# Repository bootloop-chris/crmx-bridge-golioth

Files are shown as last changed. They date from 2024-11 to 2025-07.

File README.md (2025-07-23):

# CRMX Bridge

An early demo of the [BootLoop Agent](https://bootloop.ai)!

*This repo is forked from a personal project of mine [https://github.com/chris-markus/crmx-bridge](https://github.com/chris-markus/crmx-bridge). Some clean-up commits added and upgraded to work with the most recent version of the IDF.*

Commit [77b8aad](https://github.com/bootloop-chris/crmx-bridge-golioth/commit/77b8aad5b4f520016bc5265554ae8e2e5ca4bd7b) was entirely generated and tested end-to-end by the BootLoop Agent. Email `chris [AT] bootloop [DOT] ai` for a video of the process.

---

Original README below:

Firmware and hardware for a CRMX bridge based around an ESP32s3 and a [TimoTwo module](https://lumenradio.com/products/timotwo/).

## Caveats

This is a personal project under active development. There are known (and probably unknown) bugs in the hardware. It has been open-sourced for visibility but use the hardware and firmware at your own risk!

### Known Issues

* The power button circuit has no memory outside of the microcontroller, so while downloading firmware, one of two things must be done:
  * Jump J105 to disable the power button circuit and unconditionally power the device while USB is connected
  * Hold down the power button for the duration of the software update

## Contents

* [crmx-bridge](./crmx-bridge/) - Hardware design files for the main PCBA
* [crmx-bridge-hmi](./crmx-bridge-hmi/) - Hardware design files for the Interface PCBA
* [crmx-bridge-firmware](./crmx-bridge-firmware/) - Firmware for the ESP32s3

## Firmware

Note that the firmware is pretty incomplete. It has a subset of functionality (can forward wired DMX to CRMX) but lacks control over most settings via the HMI among other omissions.

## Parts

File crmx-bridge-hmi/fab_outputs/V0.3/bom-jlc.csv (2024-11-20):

Designator | Footprint | Quantity | Value | LCSC Part #
J101 | AFC07S16FCC00 | 1 | AFC07-S16FCC-00 | C11053
R205, R207, R208 | 0402 | 3 | 10k | C25744
R206 | 0402 | 1 | 0R | C17168
R209, R210, R211 | 0603 | 3 | 150 | C22808
S201, S202, S203 | TS1187ABAB | 3 | TS-1187A-B-A-B | C318884

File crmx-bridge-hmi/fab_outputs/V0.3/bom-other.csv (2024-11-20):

Designator | Footprint | Quantity | Value | LCSC Part #
D201 | ASMBMTB00A3A2 | 1 | ASMB-MTB0-0A3A2
J201 | OLED_1.3 | 1 | Conn_01x04_Pin
U201 | PEC12R-4XXXF-SXXXX | 1 | PEC12R-4215F-S0024

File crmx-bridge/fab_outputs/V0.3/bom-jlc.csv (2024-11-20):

Designator | Footprint | Quantity | Value | LCSC Part #
C101, C102, C104, C106, C113, C114 | 0402 | 6 | 100nF | C1525
C103, C110, C111, C112 | 1206 | 4 | 22uF | C12891
C105 | 0603 | 1 | 1uF | C15849
C107 | 0603 | 1 | 10uF (50V) | C96446
C108 | 0402 | 1 | 100nF (50V) | C1525
C109 | 0603 | 1 | 100pF | C14858
C117 | 1206 | 1 | DNP | C12891
D102, D103 | D_SOD-323 | 2 | D | C191023
FB102 | 0805 | 1 | FerriteBead | C1015
IC101 | ESP32S3WROOM1UN4R2 | 1 | ESP32-S3-WROOM-1U-N4R2 | C3013942
J103 | USB_C_Receptacle_HRO_TYPE-C-31-M-12 | 1 | USB_C_Receptacle_USB2.0_16P | C165948
J106 | AFC07S16FCC00 | 1 | AFC07-S16FCC-00 | C11053
Q101 | DMTH8008LFGQ7 | 1 | DMP4025SFGQ-13 | C461091
Q102 | SOT-23 | 1 | AO3400A | C20917
R101, R102, R111, R112 | 0402 | 4 | 4k7 | C25900
R103 | 0603 | 1 | 120R (1%) | C22787
R104, R105 | 0603 | 2 | 560R (1%) | C23204
R106 | 0402 | 1 | 0R | C17168
R107, R110, R113, R121, R122, R124, R126, R127, R136 | 0402 | 9 | 10k | C25744
R108, R109 | 0603 | 2 | 27 | C25190
R115 | 0402 | 1 | 100k (1%) | C25741
R116 | 0603 | 1 | 2R | C22977
R117, R118 | 0402 | 2 | 47k (1%) | C25792
R119, R120 | 0402 | 2 | 5k1 (1%) | C25905
R123 | 0603 | 1 | 120R | C22787
R125 | 0603 | 1 | 10R (1%) | C22859
R132, R137, R138, R139, R140 | 0402 | 5 | 49R9 | C25120
R133 | 0402 | 1 | 33k | C25779
R135 | 0402 | 1 | 51k | C25794
S101, S102 | TS1187ABAB | 2 | TS-1187A-B-A-B | C318884
U102 | TSOT-23-6 | 1 | AP63200WU | C2071868
U103, U105 | SOIC-16W_7.5x10.3mm_P1.27mm | 2 | ISO3088DW | C39386
U104 | SOT-23-6 | 1 | SRV05-4 | C85364

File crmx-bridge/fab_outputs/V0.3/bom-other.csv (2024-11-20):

Designator | Footprint | Quantity | Value | LCSC Part #
J102 | Jack_XLR_Neutrik_NC3FAAH2_Horizontal | 1 | NC3FAAH2
J104 | Jack_XLR_Neutrik_NC3MAAH_Horizontal | 1 | NC3MAAH
J105 | PinHeader_1x02_P2.54mm_Vertical | 1 | Conn_01x02_Pin
L101 | L_Bourns_SRP7028A_7.3x6.6mm | 1 | 6u8H
R114 | 0402 | 1 | DNP
R134 | 0402 | 1 | DNP
TP101, TP102, TP103 | TestPoint_Pad_D1.5mm | 3 | TestPoint
U101 | MODULE_TIMOTWO | 1 | TIMOTWO
U106 | Converter_DCDC_TRACO_TEA1-xxxx_THT | 1 | TEA1-0505

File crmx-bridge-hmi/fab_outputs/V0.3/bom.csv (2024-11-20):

Designator | Footprint | Quantity | Value | LCSC Part #
D201 | ASMBMTB00A3A2 | 1 | ASMB-MTB0-0A3A2
J101 | AFC07S16FCC00 | 1 | AFC07-S16FCC-00 | C11053
J201 | OLED_1.3 | 1 | Conn_01x04_Pin
R205, R207, R208 | 0402 | 3 | 10k | C25744
R206 | 0402 | 1 | 0R | C17168
R209, R210, R211 | 0603 | 3 | 150 | C22808
S201, S202, S203 | TS1187ABAB | 3 | TS-1187A-B-A-B | C318884
U201 | PEC12R-4XXXF-SXXXX | 1 | PEC12R-4215F-S0024

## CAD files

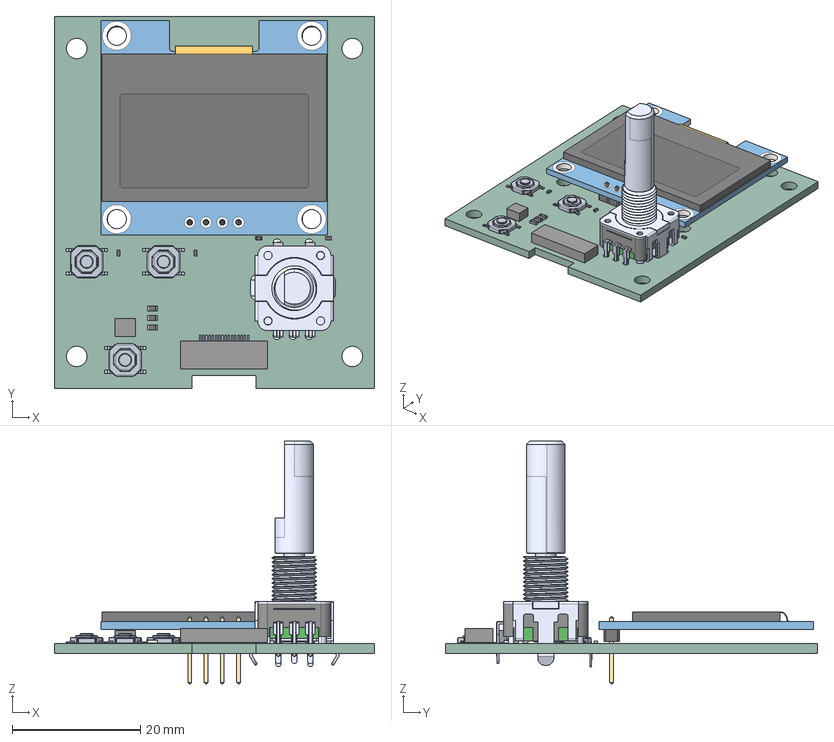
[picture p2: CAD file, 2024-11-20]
crmx-bridge-hmi/design_outputs/crmx-bridge-hmi-PCBA_V0.3.step
50.0 x 58.0 x 37.9 mm
AZ-Delivery - OLED13 IIC
R_0402_1005Metric x 4
ASSEMBLY x 2
TS-1187A-X-A-X x 3
PEC11R-4225F-S0024
R_0603_1608Metric x 3
crmx-bridge-hmi_PCB

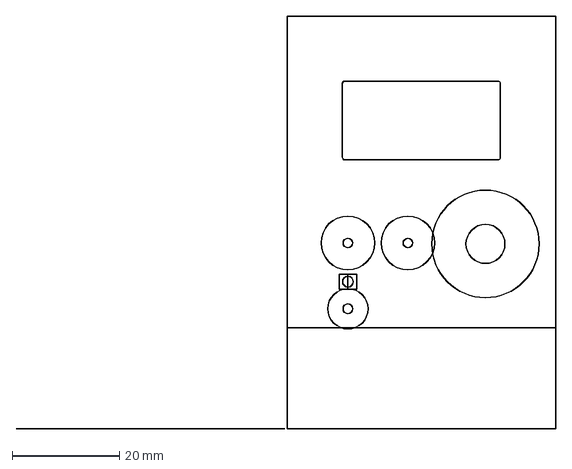
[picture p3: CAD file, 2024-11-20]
crmx-bridge/design_outputs/HMI Layout test 1.dxf
100.5 x 76.8 mm

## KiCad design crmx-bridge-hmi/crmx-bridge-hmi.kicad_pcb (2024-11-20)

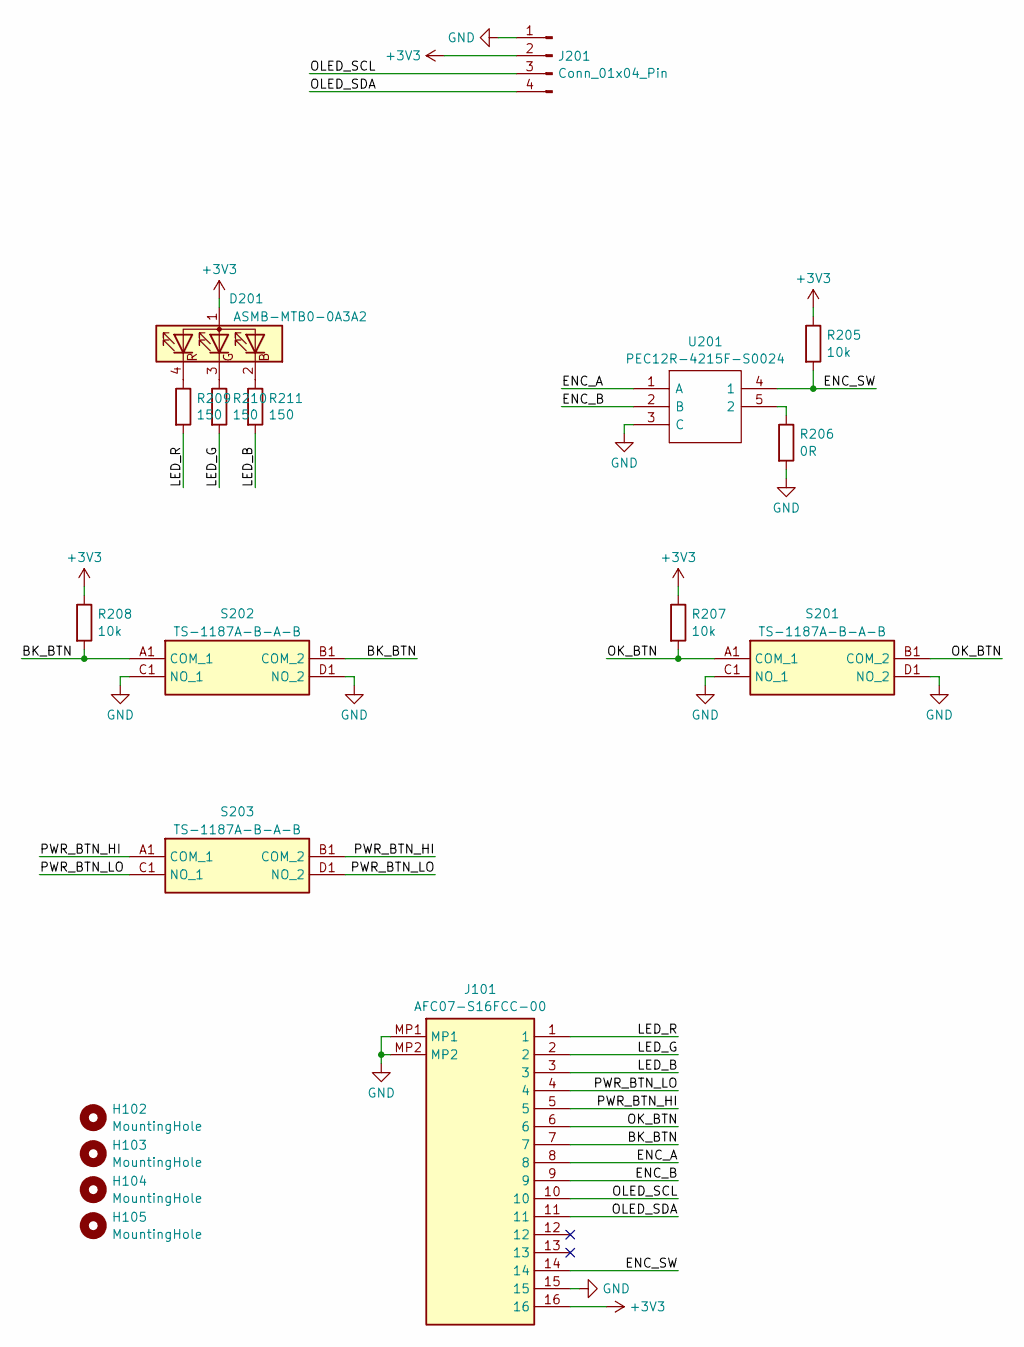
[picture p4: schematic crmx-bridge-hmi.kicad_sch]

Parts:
D201: ASMB-MTB0-0A3A2; ASMBMTB00A3A2
H102, H103, H104, H105: MountingHole; MountingHole_3.2mm_M3
J101: AFC07-S16FCC-00; AFC07S16FCC00; Manufacturer_Part_Number AFC07-S16FCC-00; LCSC C11053
J201: Conn_01x04_Pin; OLED_1.3
R205, R207, R208: 10k; R_0402_1005Metric; LCSC C25744
R206: 0R; R_0402_1005Metric; LCSC C17168
R209, R210, R211: 150; R_0603_1608Metric; LCSC C22808
S201, S202, S203: TS-1187A-B-A-B; TS1187ABAB; Manufacturer_Part_Number TS-1187A-B-A-B; LCSC C318884
U201: PEC12R-4215F-S0024; PEC12R-4XXXF-SXXXX; Manufacturer_Part_Number PEC12R-4215F-S0024; Mouser Part Number 652-PEC12R-4215F-S24

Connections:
+3V3: D201.1 (A), J101.16, J201.2, R205.1, R207.1, R208.1
/BK_BTN: J101.7, R208.2, S202.A1 (COM_1), S202.B1 (COM_2)
/ENC_A: J101.8, U201.1 (A)
/ENC_B: J101.9, U201.2 (B)
/ENC_SW: J101.14, R205.2, U201.4 (1)
/LED_B: J101.3, R211.2
/LED_G: J101.2, R210.2
/LED_R: J101.1, R209.2
/OK_BTN: J101.6, R207.2, S201.A1 (COM_1), S201.B1 (COM_2)
/OLED_SCL: J101.10, J201.3
/OLED_SDA: J101.11, J201.4
/PWR_BTN_HI: J101.5, S203.A1 (COM_1), S203.B1 (COM_2)
/PWR_BTN_LO: J101.4, S203.C1 (NO_1), S203.D1 (NO_2)
GND: J101.15, J101.MP1, J101.MP2, J201.1, R206.2, S201.C1 (NO_1), S201.D1 (NO_2), S202.C1 (NO_1), S202.D1 (NO_2), U201.3 (C)
unnamed: D201.2 (BK), R211.1
unnamed: D201.3 (GK), R210.1
unnamed: D201.4 (RK), R209.1
unnamed: R206.1, U201.5 (2)

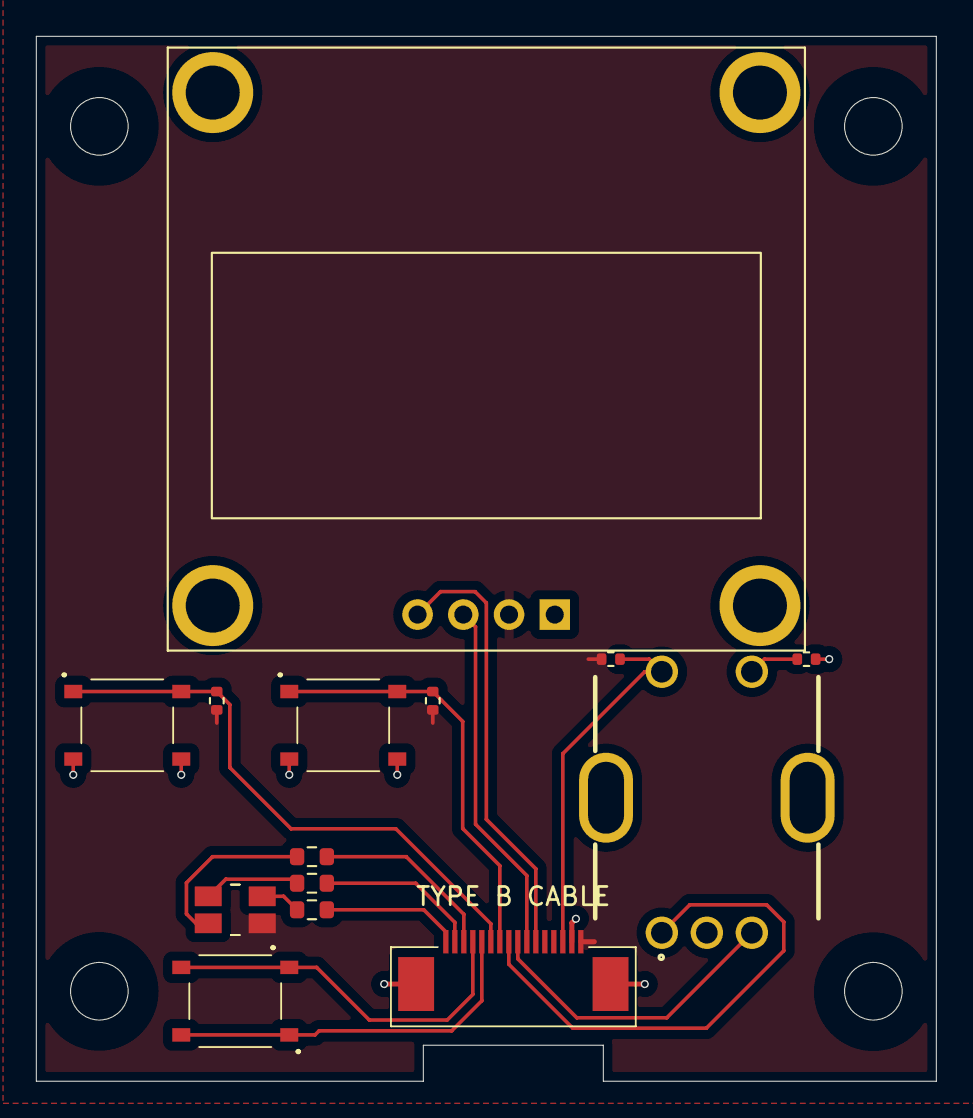
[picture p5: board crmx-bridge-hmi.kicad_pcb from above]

Board: 2 copper layers, 50.0 x 58.0 mm, 18 parts (0 on the bottom side), 18 nets.

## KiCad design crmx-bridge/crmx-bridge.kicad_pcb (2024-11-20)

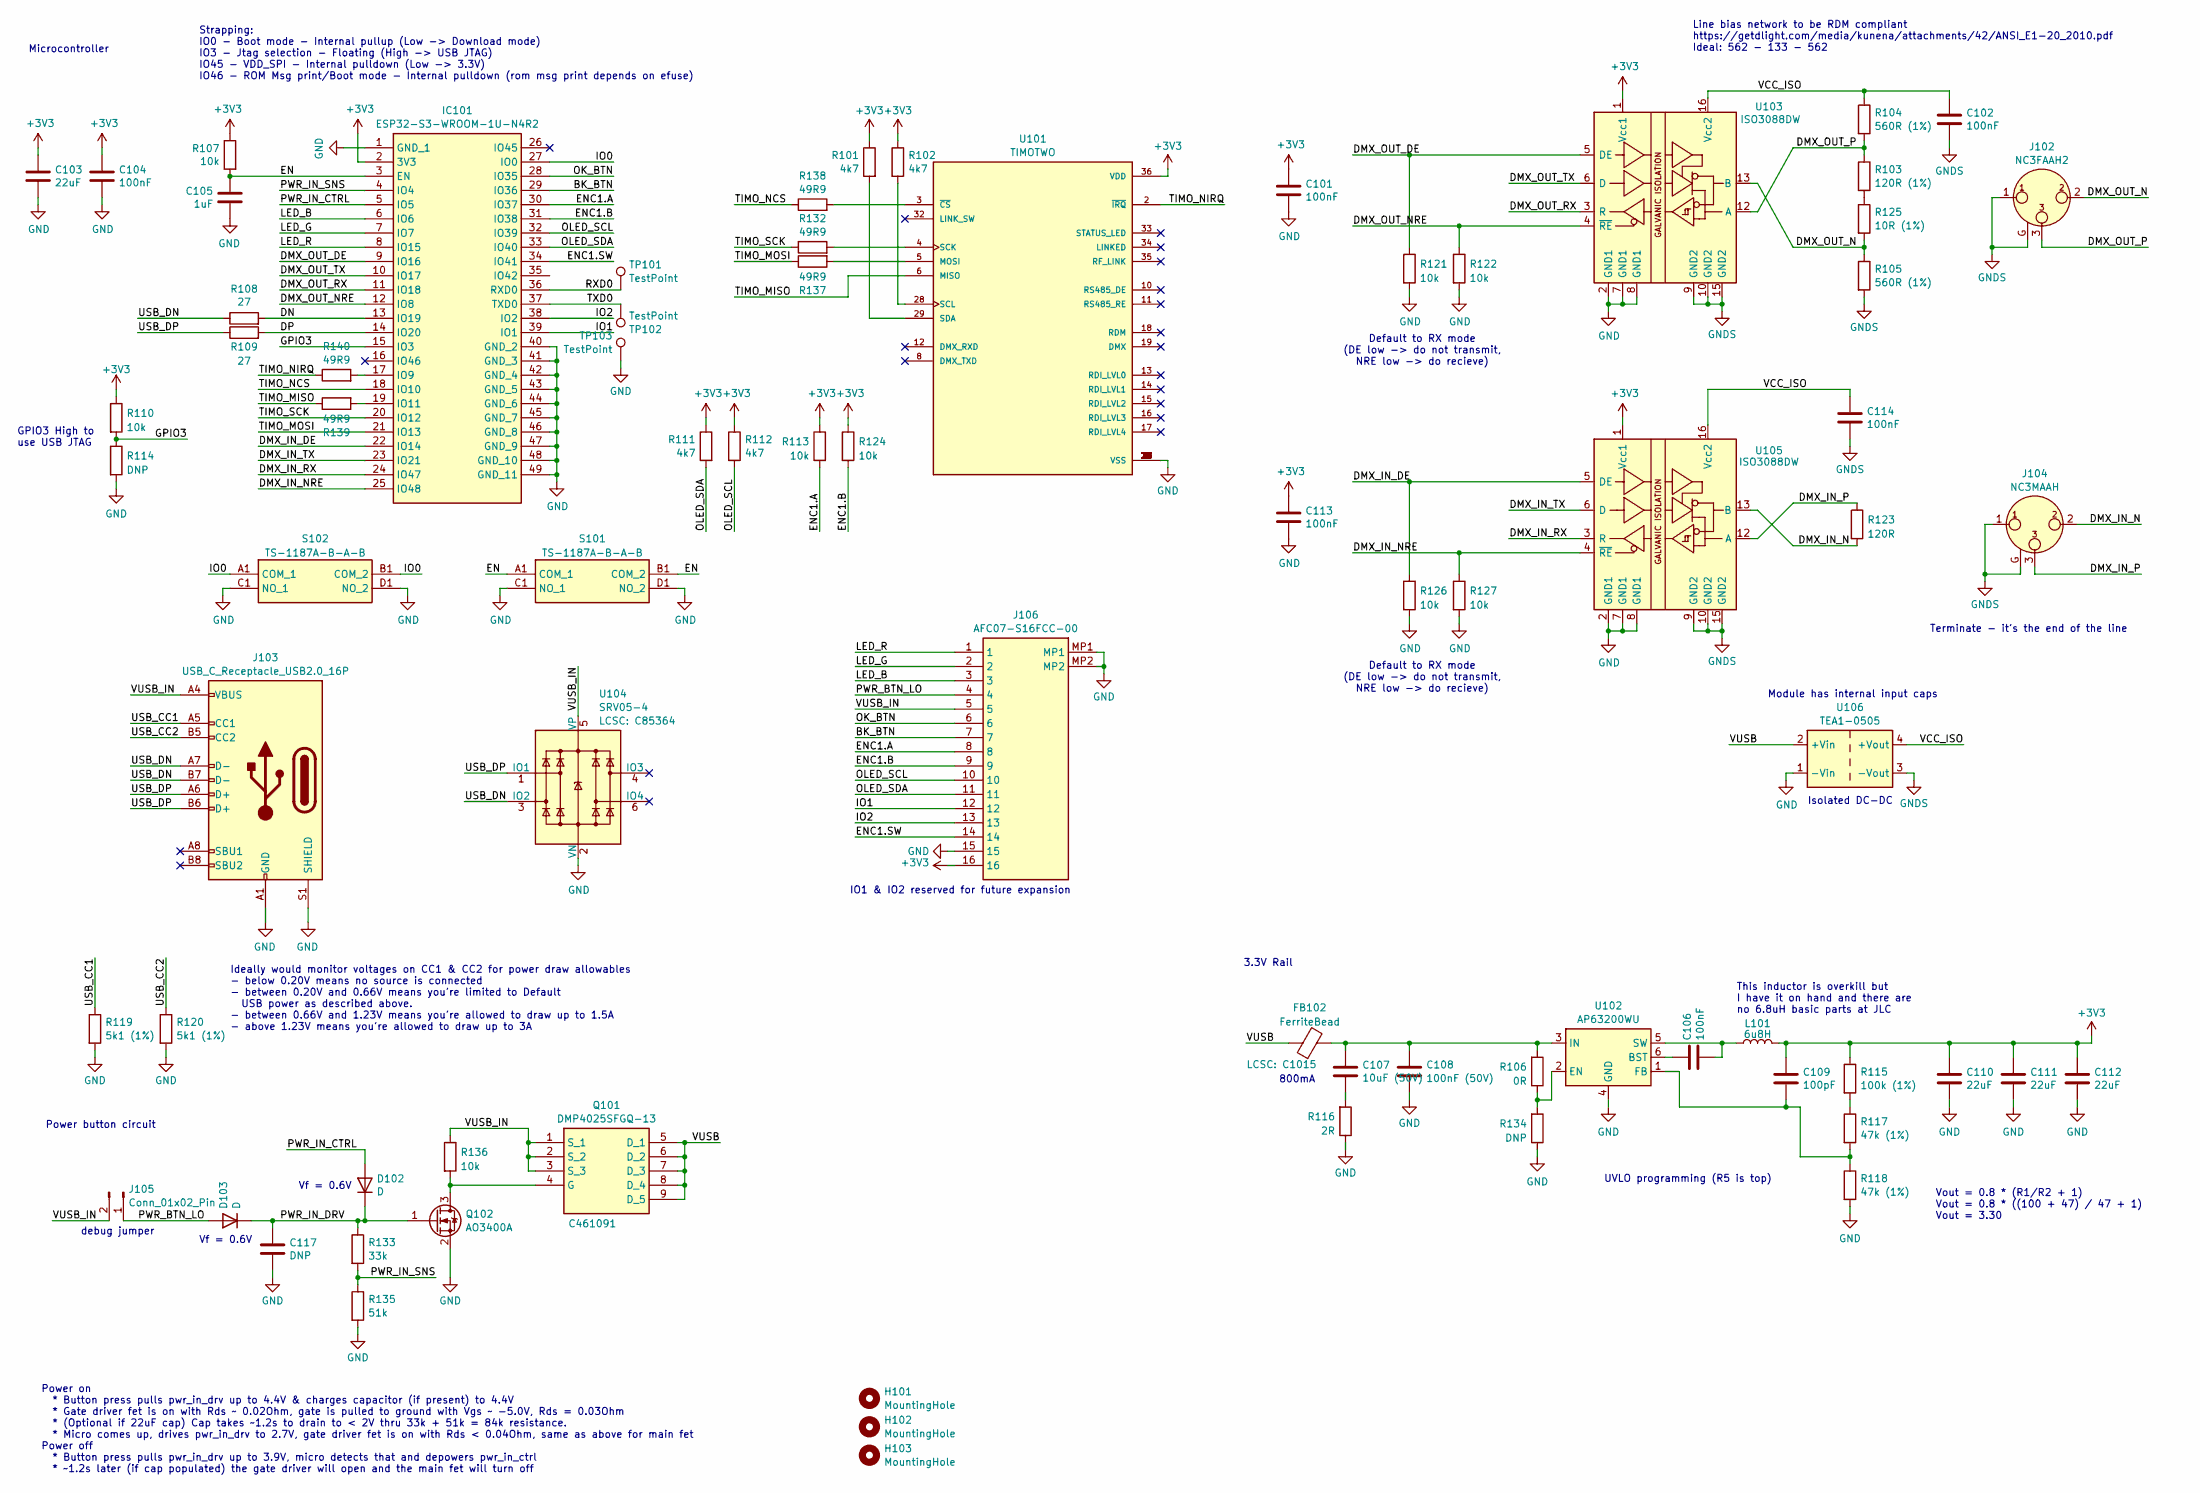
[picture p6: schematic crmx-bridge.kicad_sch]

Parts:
C101, C102, C104, C106, C113, C114: 100nF; C_0402_1005Metric; LCSC C1525
C103, C110, C111, C112: 22uF; C_1206_3216Metric; LCSC C12891
C105: 1uF; C_0603_1608Metric; LCSC C15849
C107: 10uF (50V); C_0603_1608Metric; LCSC C96446
C108: 100nF (50V); C_0402_1005Metric; LCSC C1525
C109: 100pF; C_0603_1608Metric; LCSC C14858
C117: DNP; C_1206_3216Metric; LCSC C12891
D102, D103: D; D_SOD-323; LCSC C191023
FB102: FerriteBead; C_0805_2012Metric; LCSC C1015
H101, H102, H103: MountingHole; MountingHole_3.2mm_M3
IC101: ESP32-S3-WROOM-1U-N4R2; ESP32S3WROOM1UN4R2; Manufacturer_Part_Number ESP32-S3-WROOM-1U-N4R2; Mouser Part Number 356-ESP32S3WRM1UN4R2
J102: NC3FAAH2; Jack_XLR_Neutrik_NC3FAAH2_Horizontal
J103: USB_C_Receptacle_USB2.0_16P; USB_C_Receptacle_HRO_TYPE-C-31-M-12; LCSC C165948
J104: NC3MAAH; Jack_XLR_Neutrik_NC3MAAH_Horizontal
J105: Conn_01x02_Pin; PinHeader_1x02_P2.54mm_Vertical
J106: AFC07-S16FCC-00; AFC07S16FCC00; Manufacturer_Part_Number AFC07-S16FCC-00; LCSC C11053
L101: 6u8H; L_Bourns_SRP7028A_7.3x6.6mm
Q101: DMP4025SFGQ-13; DMTH8008LFGQ7; Manufacturer_Part_Number DMPH4029LFGQ-13; Mouser Part Number 621-DMPH4029LFGQ-13
Q102: AO3400A; SOT-23; LCSC C20917
R101, R102, R111, R112: 4k7; R_0402_1005Metric; LCSC C25900
R103: 120R (1%); R_0603_1608Metric; LCSC C22787
R104, R105: 560R (1%); R_0603_1608Metric; LCSC C23204
R106: 0R; R_0402_1005Metric; LCSC C17168
R107, R110, R113, R121, R122, R124, R126, R127, R136: 10k; R_0402_1005Metric; LCSC C25744
R108, R109: 27; R_0603_1608Metric; LCSC C25190
R114, R134: DNP; R_0402_1005Metric
R115: 100k (1%); R_0402_1005Metric; LCSC C25741
R116: 2R; R_0603_1608Metric; LCSC C22977
R117, R118: 47k (1%); R_0402_1005Metric; LCSC C25792
R119, R120: 5k1 (1%); R_0402_1005Metric; LCSC C25905
R123: 120R; R_0603_1608Metric; LCSC C22787
R125: 10R (1%); R_0603_1608Metric; LCSC C22859
R132, R137, R138, R139, R140: 49R9; R_0402_1005Metric; LCSC C25120
R133: 33k; R_0402_1005Metric; LCSC C25779
R135: 51k; R_0402_1005Metric; LCSC C25794
S101, S102: TS-1187A-B-A-B; TS1187ABAB; Manufacturer_Part_Number TS-1187A-B-A-B; LCSC C318884
TP101, TP102, TP103: TestPoint; TestPoint_Pad_D1.5mm
U101: TIMOTWO; MODULE_TIMOTWO; PARTREV N/A
U102: AP63200WU; TSOT-23-6; LCSC C2071868
U103, U105: ISO3088DW; SOIC-16W_7.5x10.3mm_P1.27mm; LCSC C39386
U104: SRV05-4; SOT-23-6; LCSC C85364
U106: TEA1-0505; Converter_DCDC_TRACO_TEA1-xxxx_THT

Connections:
+3V3: C101.1, C103.1, C104.1, C109.1, C110.1, C111.1, C112.1, C113.1, IC101.2 (3V3), J106.16, L101.2, R101.1, R102.1, R107.1, R110.1, R111.1, R112.1, R113.1, R115.1, R124.1, U101.36 (VDD), U103.1 (Vcc1), U105.1 (Vcc1)
/BK_BTN: IC101.29 (IO36), J106.7
/DMX_IN_DE: IC101.22 (IO14), R126.1, U105.5 (DE)
/DMX_IN_N: J104.2, R123.2, U105.13 (B)
/DMX_IN_NRE: IC101.25 (IO48), R127.1, U105.4 (~RE)
/DMX_IN_P: J104.3, R123.1, U105.12 (A)
/DMX_IN_RX: IC101.24 (IO47), U105.3 (R)
/DMX_IN_TX: IC101.23 (IO21), U105.6 (D)
/DMX_OUT_DE: IC101.9 (IO16), R121.1, U103.5 (DE)
/DMX_OUT_N: J102.2, R105.1, R125.2, U103.13 (B)
/DMX_OUT_NRE: IC101.12 (IO8), R122.1, U103.4 (~RE)
/DMX_OUT_P: J102.3, R103.1, R104.2, U103.12 (A)
/DMX_OUT_RX: IC101.11 (IO18), U103.3 (R)
/DMX_OUT_TX: IC101.10 (IO17), U103.6 (D)
/DN: IC101.13 (IO19), R108.2
/DP: IC101.14 (IO20), R109.2
/EN: C105.1, IC101.3 (EN), R107.2, S101.A1 (COM_1), S101.B1 (COM_2)
/ENC1.A: IC101.30 (IO37), J106.8, R113.2
/ENC1.B: IC101.31 (IO38), J106.9, R124.2
/ENC1.SW: IC101.34 (IO41), J106.14
/GPIO3: IC101.15 (IO3), R110.2, R114.1
/IO0: IC101.27 (IO0), S102.A1 (COM_1), S102.B1 (COM_2)
/IO1: IC101.39 (IO1), J106.12
/IO2: IC101.38 (IO2), J106.13
/LED_B: IC101.6 (IO6), J106.3
/LED_G: IC101.7 (IO7), J106.2
/LED_R: IC101.8 (IO15), J106.1
/OK_BTN: IC101.28 (IO35), J106.6
/OLED_SCL: IC101.32 (IO39), J106.10, R112.2
/OLED_SDA: IC101.33 (IO40), J106.11, R111.2
/PWR_BTN_LO: D103.2 (A), J105.1, J106.4
/PWR_IN_CTRL: D102.2 (A), IC101.5 (IO5)
/PWR_IN_DRV: C117.1, D102.1 (K), D103.1 (K), Q102.1 (G), R133.1
/PWR_IN_SNS: IC101.4 (IO4), R133.2, R135.1
/RXD0: IC101.36 (RXD0), TP101.1
/TIMO_MISO: R139.1, U101.6 (MISO)
/TIMO_MOSI: IC101.21 (IO13), R137.1
/TIMO_NCS: IC101.18 (IO10), R138.1
/TIMO_NIRQ: R140.1, U101.2 (~IRQ)
/TIMO_SCK: IC101.20 (IO12), R132.1
/TXD0: IC101.37 (TXD0), TP102.1
/USB_CC1: J103.A5 (CC1), R119.1
/USB_CC2: J103.B5 (CC2), R120.1
/USB_DN: J103.A7 (D-), J103.B7 (D-), R108.1, U104.3 (IO2)
/USB_DP: J103.A6 (D+), J103.B6 (D+), R109.1, U104.1 (IO1)
/VCC_ISO: C102.1, C114.1, R104.1, U103.16 (Vcc2), U105.16 (Vcc2), U106.4 (+Vout)
/VUSB: FB102.1, Q101.5 (D_1), Q101.6 (D_2), Q101.7 (D_3), Q101.8 (D_4), Q101.9 (D_5), U106.2 (+Vin)
/VUSB_IN: J103.A4 (VBUS), J103.A9 (VBUS), J103.B4 (VBUS), J103.B9 (VBUS), J105.2, J106.5, Q101.1 (S_1), Q101.2 (S_2), Q101.3 (S_3), R136.1, U104.5 (VP)
GND: C101.2, C103.2, C104.2, C105.2, C108.2, C110.2, C111.2, C112.2, C113.2, C117.2, IC101.1 (GND_1), IC101.40 (GND_2), IC101.41 (GND_3), IC101.42 (GND_4), IC101.43 (GND_5), IC101.44 (GND_6), IC101.45 (GND_7), IC101.46 (GND_8), IC101.47 (GND_9), IC101.48 (GND_10), IC101.49 (GND_11), J103.A1 (GND), J103.A12 (GND), J103.B1 (GND), J103.B12 (GND), J103.S1 (SHIELD), J106.15, J106.MP1, J106.MP2, Q102.2 (S), R114.2, R116.1, R118.2, R119.2, R120.2, R121.2, R122.2, R126.2, R127.2, R134.1, R135.2, S101.C1 (NO_1), S101.D1 (NO_2), S102.C1 (NO_1), S102.D1 (NO_2), TP103.1, U101.1 (VSS), U101.7 (VSS), U101.9 (VSS), U101.22 (VSS), U101.23 (VSS), U101.24 (VSS), U101.25 (VSS), U101.26 (VSS), U101.27 (VSS), U101.30 (VSS), U101.37 (VSS), U102.4 (GND), U103.2 (GND1), U103.7 (GND1), U103.8 (GND1), U104.2 (VN), U105.2 (GND1), U105.7 (GND1), U105.8 (GND1), U106.1 (-Vin)
GNDS: C102.2, C114.2, J102.1, J102.G, J104.1, J104.G, R105.2, U103.9 (GND2), U103.10 (GND2), U103.15 (GND2), U105.9 (GND2), U105.10 (GND2), U105.15 (GND2), U106.3 (-Vout)
unnamed: C107.2, R116.2
unnamed: IC101.17 (IO9), R140.2
unnamed: IC101.19 (IO11), R139.2
unnamed: Q101.4 (G), Q102.3 (D), R136.2
unnamed: R103.2, R125.1
unnamed: R115.2, R117.1
unnamed: R137.2, U101.5 (MOSI)
unnamed: R132.2, U101.4 (SCK)
unnamed: R102.2, U101.28 (SCL)
unnamed: R101.2, U101.29 (SDA)
unnamed: R138.2, U101.3 (~CS)
unnamed: C106.1, U102.6 (BST)
unnamed: R106.1, R134.2, U102.2 (EN)
unnamed: C109.2, R117.2, R118.1, U102.1 (FB)
unnamed: C107.1, C108.1, FB102.2, R106.2, U102.3 (IN)
unnamed: C106.2, L101.1, U102.5 (SW)

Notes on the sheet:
Power on * Button press pulls pwr_in_drv up to 4.4V & charges capacitor (if present) to 4.4V * Gate driver fet is on with Rds ~ 0.02Ohm, gate is pulled to ground with Vgs ~ -5.0V, Rds = 0.03Ohm * (Optional if 22uF cap) Cap takes ~1.2s to drain to < 2V thru 33k + 51k = 84k resistance. * Micro comes 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
Vout = 0.8 * (R1/R2 + 1) Vout = 0.8 * ((100 + 47) / 47 + 1) Vout = 3.30
Vf = 0.6V
GPIO3 High to use USB JTAG
Strapping: IO0 - Boot mode - Internal pullup (Low -> Download mode) IO3 - Jtag selection - Floating (High -> USB JTAG) IO45 - VDD_SPI - Internal pulldown (Low -> 3.3V) IO46 - ROM Msg print/Boot mode - Internal pulldown (rom msg print depends on efuse)
debug jumper
3.3V Rail
Isolated DC-DC
IO1 & IO2 reserved for future expansion
Ideally would monitor voltages on CC1 & CC2 for power draw allowables - below 0.20V means no source is connected - between 0.20V and 0.66V means you're limited to Default USB power as described above. - between 0.66V and 1.23V means you're allowed to draw up to 1.5A - above 1.23V means you're allow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
UVLO programming (R5 is top)
800mA
Default to RX mode (DE low -> do not transmit, NRE low -> do recieve)
Power button circuit
Terminate - it's the end of the line
Microcontroller
Module has internal input caps
Line bias network to be RDM compliant https://getdlight.com/media/kunena/attachments/42/ANSI_E1-20_2010.pdf Ideal: 562 - 133 - 562
This inductor is overkill but I have it on hand and there are no 6.8uH basic parts at JLC

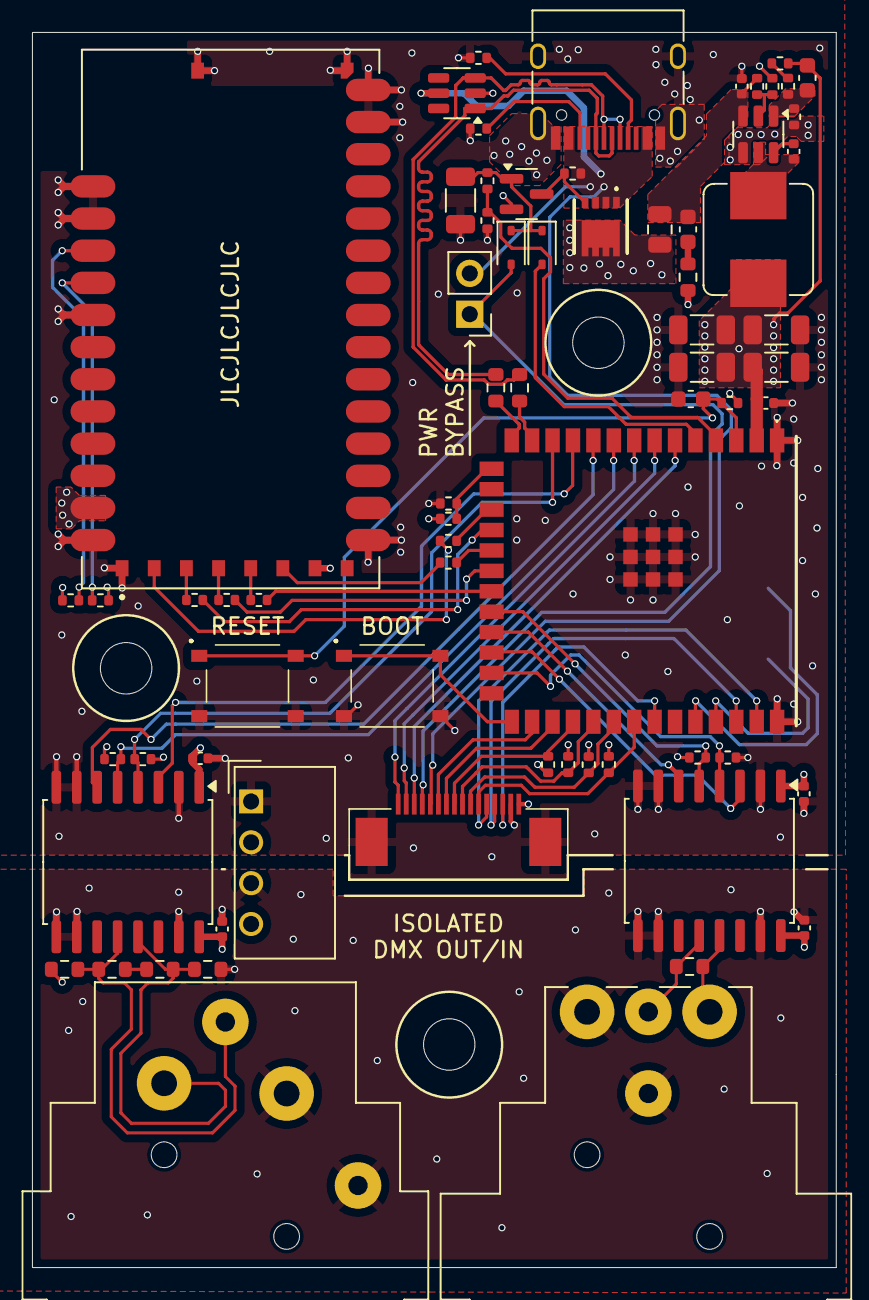
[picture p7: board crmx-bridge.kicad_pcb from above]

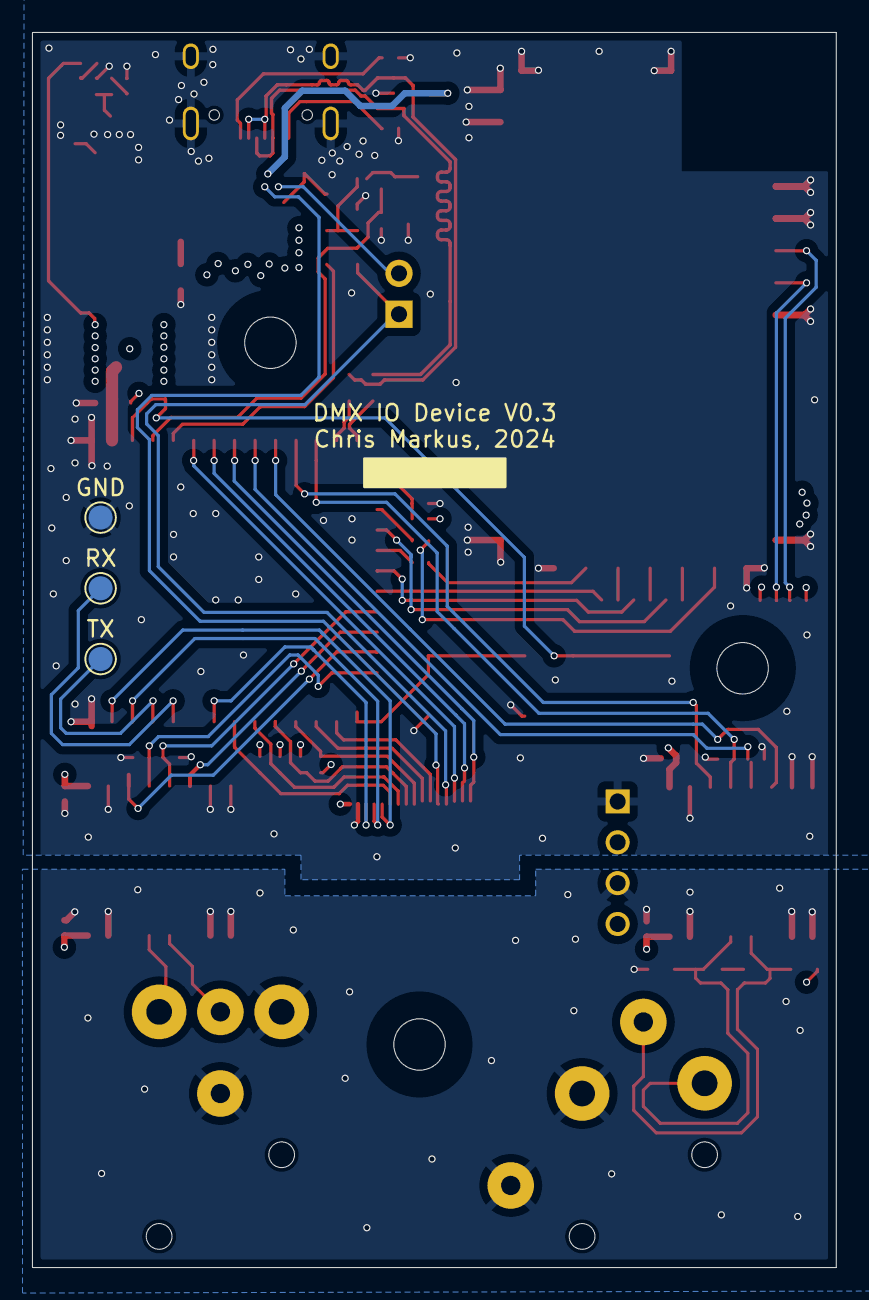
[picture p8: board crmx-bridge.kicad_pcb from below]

Board: 4 copper layers, 50.0 x 76.8 mm, 77 parts (3 on the bottom side), 66 nets.

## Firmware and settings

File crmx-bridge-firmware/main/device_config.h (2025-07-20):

#pragma once

// Default WiFi credentials (can be overridden via NVS or Golioth settings)
#define DEFAULT_WIFI_SSID    ""  // Set your default WiFi SSID here
#define DEFAULT_WIFI_PASS    ""  // Set your default WiFi password here

// Default Golioth credentials (can be overridden via NVS)
#define DEFAULT_GOLIOTH_PSK_ID  ""  // Set your Golioth PSK ID here
#define DEFAULT_GOLIOTH_PSK     ""  // Set your Golioth PSK here - You'll need to provide this

// Telemetry reporting interval
#define TELEMETRY_INTERVAL_MS   (30 * 1000)  // 30 seconds

// Enable/disable features
#define ENABLE_GOLIOTH_LOGS     1
#define ENABLE_TELEMETRY        1
#define ENABLE_OTA_UPDATES      1

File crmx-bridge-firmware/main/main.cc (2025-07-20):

#include "DmxSwitcher.h"
#include "SettingsHandler.h"
#include "TimoInterface.h"
#include "wifi_task.h"
#include "wifi_manager.h"
#include "device_config.h"
#include "driver/gpio.h"
#include "driver/i2c_master.h"
#include "driver/ledc.h"
#include "driver/spi_master.h"
#include "esp_adc/adc_cali.h"
#include "esp_adc/adc_cali_scheme.h"
#include "esp_adc/adc_oneshot.h"
#include "esp_dmx.h"
#include "esp_err.h"
#include "esp_lcd_panel_io.h"
#include "esp_lcd_panel_ops.h"
#include "esp_lcd_panel_vendor.h"
#include "esp_log.h"
#include "esp_lvgl_port.h"
#include "esp_timer.h"
#include "freertos/FreeRTOS.h"
#include "freertos/task.h"
#include "limits.h"
#include "lvgl.h"
#include "rotary_encoder.h"
#include "soc/soc_caps.h"
#include "ssd1106.h"
#include "ui/ui.h"
#include <stdio.h>
#include <stdlib.h>
#include <string.h>

#define LCD_PIXEL_CLOCK_HZ (400 * 1000)
#define PIN_NUM_SDA 40
#define PIN_NUM_SCL 39
#define PIN_NUM_RST -1
#define I2C_HW_ADDR 0x3C

// The pixel number in horizontal and vertical
#define LCD_H_RES 128
#define LCD_V_RES 64
// Bit number used to represent command and parameter
#define LCD_CMD_BITS 8
#define LCD_PARAM_BITS 8

const static char *TAG = "main";

static constexpr adc_channel_t pwr_btn_sns_chann = ADC_CHANNEL_3;
static constexpr gpio_num_t pwr_in_ctrl_pin = GPIO_NUM_37;
static constexpr int pwr_btn_press_thresh_mv = 2500;

static constexpr spi_host_device_t timo_spi_bus = SPI2_HOST;
static constexpr spi_bus_config_t spi_bus_cfg = {
    .mosi_io_num = GPIO_NUM_13,
    .miso_io_num = GPIO_NUM_11,
    .sclk_io_num = GPIO_NUM_12,
    .quadwp_io_num = -1,
    .quadhd_io_num = -1,
    .max_transfer_sz = 0,
};

// The SPI configuration for the TimoTwo CRMX Module
static constexpr TimoHardwareConfig timo_config = {
    .nirq_pin = GPIO_NUM_9,
    .spi_devcfg =
        {
            .mode = 0, // SPI mode 0 (CPOL 0, CPHA0)
            .cs_ena_pretrans = 6,
            .clock_speed_hz = 1 * 1000 * 1000, // 1 MHz
            .spics_io_num = GPIO_NUM_10,       // CS pin
            .queue_size = 1,
        },
};

TimoInterface timo_interface{timo_config};

static constexpr gpio_num_t led_r_pin = GPIO_NUM_15;
static constexpr gpio_num_t led_g_pin = GPIO_NUM_7;
static constexpr gpio_num_t led_b_pin = GPIO_NUM_6;
static constexpr gpio_num_t btn_ok_pin = GPIO_NUM_35;
static constexpr gpio_num_t btn_bk_pin = GPIO_NUM_36;
static constexpr gpio_num_t btn_enc_pin = GPIO_NUM_41;
static constexpr gpio_num_t enc_a_pin = GPIO_NUM_37;
static constexpr gpio_num_t enc_b_pin = GPIO_NUM_38;

// DMX Configuration for physical input and output ports
struct dmx_port_config_t {
  dmx_port_t port;
  int tx_pin;
  int rx_pin;
  gpio_num_t de_pin;
  gpio_num_t nre_pin;
};
static constexpr dmx_port_config_t dmx_in_cfg = {
    .port = DMX_NUM_0,
    .tx_pin = 21,
    .rx_pin = 47,
    .de_pin = GPIO_NUM_14,
    .nre_pin = GPIO_NUM_48,
};
static constexpr dmx_port_config_t dmx_out_cfg = {
    .port = DMX_NUM_1,
    .tx_pin = 17,
    .rx_pin = 18,
    .de_pin = GPIO_NUM_16,
    .nre_pin = GPIO_NUM_8,
};

// Encoder
QueueHandle_t encoder_queue = nullptr;

static void set_led_color(const RGBColor &color) {
  ledc_set_duty_and_update(LEDC_LOW_SPEED_MODE, LEDC_CHANNEL_0, color.red, 0);
  ledc_set_duty_and_update(LEDC_LOW_SPEED_MODE, LEDC_CHANNEL_1, color.green, 0);
  ledc_set_duty_and_update(LEDC_LOW_SPEED_MODE, LEDC_CHANNEL_2, color.blue, 0);
}

/**
 * DMX Task for physical DMX IO
 */
extern "C" void onboard_dmx_task(void *pvParameters) {
  DmxInterface *interface = static_cast<DmxInterface *>(pvParameters);

  if (interface == nullptr) {
    ESP_LOGE(TAG, "Invalid DMX Interface");
    return;
  }

  // First, use the default DMX configuration...
  dmx_config_t dmx_config = DMX_CONFIG_DEFAULT;

  // Install the send and recieve drivers.
  dmx_driver_install(dmx_in_cfg.port, &dmx_config, nullptr, 0);
  dmx_driver_install(dmx_out_cfg.port, &dmx_config, nullptr, 0);

  // Set the pins for both drivers.
  dmx_set_pin(dmx_in_cfg.port, dmx_in_cfg.tx_pin, dmx_in_cfg.rx_pin, -1);
  dmx_set_pin(dmx_out_cfg.port, dmx_out_cfg.tx_pin, dmx_out_cfg.rx_pin, -1);

  // Configure DE/RE pins (true = tx; false = rx).
  ESP_ERROR_CHECK(gpio_set_level(dmx_in_cfg.nre_pin, false));
  ESP_ERROR_CHECK(gpio_set_level(dmx_in_cfg.de_pin, false));
  ESP_ERROR_CHECK(gpio_set_level(dmx_out_cfg.nre_pin, true));
  ESP_ERROR_CHECK(gpio_set_level(dmx_out_cfg.de_pin, true));

  gpio_config_t dmx_io_conf = {
      .pin_bit_mask =
          (1ULL << dmx_in_cfg.de_pin) | (1ULL << dmx_in_cfg.nre_pin) |
          (1ULL << dmx_out_cfg.de_pin) | (1ULL << dmx_out_cfg.nre_pin),
      .mode = GPIO_MODE_OUTPUT,
      .pull_up_en = GPIO_PULLUP_DISABLE,
      .pull_down_en = GPIO_PULLDOWN_DISABLE,
      .intr_type = GPIO_INTR_DISABLE,
  };

  ESP_ERROR_CHECK(gpio_config(&dmx_io_conf));

  dmx_packet_t rx_meta;

  DmxPacket tx_packet;
  DmxPacket rx_packet;

  ESP_LOGI(TAG, "Finished Onboard DMX Init");

  while (true) {
    if (dmx_receive(dmx_in_cfg.port, &rx_meta, DMX_TIMEOUT_TICK)) {
      if (rx_meta.err != DMX_OK ||
          rx_meta.size > sizeof(rx_packet.full_packet)) {
        ESP_LOGE(TAG, "DMX Packet Error: %d, %zu", rx_meta.err, rx_meta.size);
      } else {
        size_t data_len = dmx_read(dmx_in_cfg.port, &rx_packet.full_packet,
                                   rx_packet.full_packet.size());
        if (data_len == rx_packet.full_packet.size()) {
          interface->send(rx_packet);
        } else {
          ESP_LOGE(TAG, "Recieved short DMX packet: %zu", data_len);
        }
      }
    }

    if (interface->recieve(tx_packet, 0)) {
      size_t written_len = dmx_write(dmx_out_cfg.port, &tx_packet.full_packet,
                                     tx_packet.full_packet.size());
      if (written_len != tx_packet.full_packet.size()) {
        ESP_LOGE(TAG, "Wrote short DMX Packet: %zu", written_len);
      }
      written_len = dmx_send(dmx_out_cfg.port);
      if (written_len != tx_packet.full_packet.size()) {
        ESP_LOGE(TAG, "Sent short DMX Packet: %zu", written_len);
      }
    }
    vTaskDelay(pdMS_TO_TICKS(2));
  }
}

/**
 * Delegate implementation to notify a task when settings are changed
 */
class TaskNotifySettingsDelegate : public SettingsChangeDelegate {
public:
  TaskNotifySettingsDelegate(TaskHandle_t _task_handle)
      : task_handle(_task_handle) {}

  void on_settings_update(const SettingsHandler &settings) override {
    if (task_handle != nullptr) {
      xTaskNotify(task_handle, true, eSetValueWithOverwrite);
    }
  }

private:
  TaskHandle_t task_handle;
};

/**
 * Construct a Timo software config from the values stored in NVS
 */
static TimoSoftwareConfig timo_config_from_settings() {
  SettingsHandler &settings = SettingsHandler::shared();

  using namespace TIMO;
  return TimoSoftwareConfig{
      .radio_en = settings.get_timo_radio_en(),
      .tx_rx_mode = settings.get_timo_tx_rx(),
      .rf_protocol = settings.rf_protocol,
      .dmx_source = DMX_SOURCE::DATA_SOURCE_T::NO_DATA,
      .rf_power = settings.tmo_opt_pwr,
      .universe_color = settings.get_universe_color(),
      .device_name = "CRMXBridge",
  };
}

/**
 * Run the TimoTwo interface
 */
extern "C" void timo_dmx_task(void *pvParameters) {
  DmxInterface *interface = static_cast<DmxInterface *>(pvParameters);

  if (interface == nullptr) {
    ESP_LOGE(TAG, "Invalid DMX Interface");
    return;
  }

  // Give TIMO a while to power on.
  vTaskDelay(pdMS_TO_TICKS(2000));

  // Initialize the SPI bus
  ESP_ERROR_CHECK(
      spi_bus_initialize(timo_spi_bus, &spi_bus_cfg, SPI_DMA_CH_AUTO));
  ESP_ERROR_CHECK(timo_interface.init(timo_spi_bus));

  // Settings are user-generated and therefore fallable. Allow boot to continue
  // even if setting settings fails.
  ESP_ERROR_CHECK_WITHOUT_ABORT(
      timo_interface.set_sw_config(timo_config_from_settings()));

  ESP_LOGI(TAG, "Finished Timo Init");

  int64_t last_print = esp_timer_get_time();

  TickType_t xLastWakeTime = xTaskGetTickCount();
  DmxPacket packet{};

  // Loop over the recieved frames and transmit them
  while (true) {
    // Interface -> recieve blocks
    if (interface->recieve(packet, pdMS_TO_TICKS(5))) {
      if (timo_interface.write_dmx(packet.full_packet.data) != ESP_OK) {
        ESP_LOGE(TAG, "Failed to write dmx from source %d",
                 static_cast<int>(packet.source));
      }
    }

    // If a notification was recieved, a settings update occurred.
    if (xTaskNotifyWait(0b1, 0, NULL, 0) == pdTRUE) {
      TimoSoftwareConfig new_config = timo_config_from_settings();
      if (new_config != timo_interface.get_sw_config()) {
        timo_interface.set_sw_config(new_config);
      }
    }

    vTaskDelayUntil(&xLastWakeTime, pdMS_TO_TICKS(2));
  }
}

void init_led() {

  static constexpr auto SPEED_MODE = LEDC_LOW_SPEED_MODE;
  static constexpr auto TIMER = LEDC_TIMER_0;

  // Prepare and then apply the LEDC PWM timer configuration
  ledc_timer_config_t ledc_timer = {
      .speed_mode = SPEED_MODE,
      .duty_resolution = LEDC_TIMER_8_BIT,
      .timer_num = TIMER,
      .freq_hz = 4000, // Set output frequency at 4 kHz
      .clk_cfg = LEDC_AUTO_CLK,
  };
  ESP_ERROR_CHECK(ledc_timer_config(&ledc_timer));

  static constexpr std::array<gpio_num_t, 3> led_pins = {
      {led_r_pin, led_g_pin, led_b_pin}};
  static constexpr std::array<ledc_channel_t, 3> led_channels = {
      {LEDC_CHANNEL_0, LEDC_CHANNEL_1, LEDC_CHANNEL_2}};

  for (size_t i = 0; i < 3; i++) {
    ledc_channel_config_t ledc_channel = {
        .gpio_num = led_pins[i],
        .speed_mode = SPEED_MODE,
        .channel = led_channels[i],
        .intr_type = LEDC_INTR_DISABLE,
        .timer_sel = TIMER,
        .duty = 0, // Set duty to 0%
        .hpoint = 0,
        .flags = {.output_invert = 1},
    };
    ESP_ERROR_CHECK(ledc_channel_config(&ledc_channel));
  }
  ESP_ERROR_CHECK(ledc_fade_func_install(0));

  set_led_color(SettingsHandler::shared().get_universe_color());
}


int16_t enc_get_new_moves() {
  static int32_t last_position = 0;

  if (!encoder_queue) {
    return 0;
  }

  rotary_encoder_event_t event = {0};
  if (xQueueReceive(encoder_queue, &event, 0) == pdTRUE) {
    const int16_t val =
        static_cast<int16_t>(last_position - event.state.position);
    last_position = event.state.position;
    return val;
  }
  return 0;
}

void encoder_read(lv_indev_t *indev, lv_indev_data_t *data) {
  data->enc_diff = enc_get_new_moves();

  if (gpio_get_level(btn_enc_pin))
    data->state = LV_INDEV_STATE_RELEASED;
  else
    data->state = LV_INDEV_STATE_PRESSED;
}

void init_lvgl() {
  // From LVGL monochrome example
  ESP_LOGI(TAG, "Initialize I2C bus");
  i2c_master_bus_handle_t i2c_bus = NULL;
  i2c_master_bus_config_t bus_config = {
      .i2c_port = I2C_NUM_0,
      .sda_io_num = GPIO_NUM_40,
      .scl_io_num = GPIO_NUM_39,
      .clk_source = I2C_CLK_SRC_DEFAULT,
      .glitch_ignore_cnt = 7,
      .flags =
          {
              .enable_internal_pullup = true,
          },
  };
  ESP_ERROR_CHECK(i2c_new_master_bus(&bus_config, &i2c_bus));

  ESP_LOGI(TAG, "Install SSD1106 panel IO");
  esp_lcd_panel_io_handle_t io_handle = NULL;
  esp_lcd_panel_io_i2c_config_t io_config = {
      .dev_addr = I2C_HW_ADDR,
      .user_ctx = nullptr,
      .control_phase_bytes = 1,
      .dc_bit_offset = 6,
      .lcd_cmd_bits = LCD_CMD_BITS,
      .lcd_param_bits = LCD_PARAM_BITS,
      .scl_speed_hz = LCD_PIXEL_CLOCK_HZ,
  };
  ESP_ERROR_CHECK(esp_lcd_new_panel_io_i2c_v2(i2c_bus, &io_config, &io_handle));

  esp_lcd_panel_handle_t panel_handle = NULL;
  esp_lcd_panel_dev_config_t panel_config = {
      .reset_gpio_num = -1,
      .bits_per_pixel = 1,
  };

  ESP_LOGI(TAG, "Installing SSD1106 panel driver");
  ESP_ERROR_CHECK(new_ssd1106(io_handle, &panel_config, &panel_handle));

  ESP_ERROR_CHECK(esp_lcd_panel_reset(panel_handle));
  ESP_ERROR_CHECK(esp_lcd_panel_init(panel_handle));
  ESP_ERROR_CHECK(esp_lcd_panel_disp_on_off(panel_handle, true));

  ESP_LOGI(TAG, "Initializing LVGL");
  const lvgl_port_cfg_t lvgl_cfg = ESP_LVGL_PORT_INIT_CONFIG();
  lvgl_port_init(&lvgl_cfg);

  const lvgl_port_display_cfg_t disp_cfg = {
      .io_handle = io_handle,
      .panel_handle = panel_handle,
      .buffer_size = LCD_H_RES * LCD_V_RES,
      .double_buffer = true,
      .hres = LCD_H_RES,
      .vres = LCD_V_RES,
      .monochrome = true,
      .rotation =
          {
              .swap_xy = false,
              .mirror_x = false,
              .mirror_y = false,
          },
      .color_format = LV_COLOR_FORMAT_RGB565,
      .flags =
          {
              .sw_rotate = false,
              .swap_bytes = false,
              .full_refresh = true,
              .direct_mode = true,
          },
  };
  lv_disp_t *disp = lvgl_port_add_disp(&disp_cfg);

  // Setup input device
  lv_indev_t *indev = lv_indev_create();
  lv_indev_set_type(indev, LV_INDEV_TYPE_ENCODER);
  lv_indev_set_read_cb(indev, encoder_read);

  // Lock the mutex - LVGL APIs are not thread-safe
  if (lvgl_port_lock(0)) {
    // Init the UI
    lv_disp_set_rotation(disp, LV_DISPLAY_ROTATION_0);
    ui_init();

    // Release the mutex
    lvgl_port_unlock();
  }
}

void hmi_task(void *pvParameters) {

  // Encoder
  rotary_encoder_info_t encoder = {};
  ESP_ERROR_CHECK(gpio_install_isr_service(0));
  ESP_ERROR_CHECK(rotary_encoder_init(&encoder, enc_a_pin, enc_b_pin));
  ESP_ERROR_CHECK(rotary_encoder_enable_half_steps(&encoder, false));

  // Create a queue for events from the rotary encoder driver.
  // Tasks can read from this queue to receive up to date position
  // information.
  encoder_queue = rotary_encoder_create_queue();
  ESP_ERROR_CHECK(rotary_encoder_set_queue(&encoder, encoder_queue));

  const gpio_config_t config = {
      .pin_bit_mask = (1ULL << btn_enc_pin),
      .mode = GPIO_MODE_INPUT,
      .pull_up_en = GPIO_PULLUP_DISABLE,
      .pull_down_en = GPIO_PULLDOWN_DISABLE,
      .intr_type = GPIO_INTR_DISABLE,
  };
  ESP_ERROR_CHECK(gpio_config(&config));

  // RGB LED
  init_led();

  TickType_t xLastWakeTime = xTaskGetTickCount();

  while (1) {
    if (gpio_get_level(btn_bk_pin)) {
      // TODO: implement back button functionality
    }

    // Always set the LED to the CRMX universe color for now
    set_led_color(SettingsHandler::shared().get_universe_color());
  
    vTaskDelayUntil(&xLastWakeTime, pdMS_TO_TICKS(50));
  }
  ESP_ERROR_CHECK(rotary_encoder_uninit(&encoder));
}

/**
 * ADC Calibration
 */
static bool adc_calibration_init(adc_unit_t unit, adc_channel_t channel,
                                 adc_atten_t atten,
                                 adc_cali_handle_t *out_handle) {
  adc_cali_handle_t handle = NULL;
  esp_err_t ret = ESP_FAIL;
  bool calibrated = false;

#if ADC_CALI_SCHEME_CURVE_FITTING_SUPPORTED
  if (!calibrated) {
    ESP_LOGI(TAG, "calibration scheme version is %s", "Curve Fitting");
    adc_cali_curve_fitting_config_t cali_config = {
        .unit_id = unit,
        .chan = channel,
        .atten = atten,
        .bitwidth = ADC_BITWIDTH_DEFAULT,
    };
    ret = adc_cali_create_scheme_curve_fitting(&cali_config, &handle);
    if (ret == ESP_OK) {
      calibrated = true;
    }
  }
#endif

#if ADC_CALI_SCHEME_LINE_FITTING_SUPPORTED
  if (!calibrated) {
    ESP_LOGI(TAG, "calibration scheme version is %s", "Line Fitting");
    adc_cali_line_fitting_config_t cali_config = {
        .unit_id = unit,
        .atten = atten,
        .bitwidth = ADC_BITWIDTH_DEFAULT,
    };
    ret = adc_cali_create_scheme_line_fitting(&cali_config, &handle);
    if (ret == ESP_OK) {
      calibrated = true;
    }
  }
#endif

  *out_handle = handle;
  if (ret == ESP_OK) {
    ESP_LOGI(TAG, "Calibration Success");
  } else if (ret == ESP_ERR_NOT_SUPPORTED || !calibrated) {
    ESP_LOGW(TAG, "eFuse not burnt, skip software calibration");
  } else {
    ESP_LOGE(TAG, "Invalid arg or no memory");
  }

  return calibrated;
}

static void adc_calibration_deinit(adc_cali_handle_t handle) {
#if ADC_CALI_SCHEME_CURVE_FITTING_SUPPORTED
  ESP_LOGI(TAG, "deregister %s calibration scheme", "Curve Fitting");
  ESP_ERROR_CHECK(adc_cali_delete_scheme_curve_fitting(handle));

#elif ADC_CALI_SCHEME_LINE_FITTING_SUPPORTED
  ESP_LOGI(TAG, "deregister %s calibration scheme", "Line Fitting");
  ESP_ERROR_CHECK(adc_cali_delete_scheme_line_fitting(handle));
#endif
}

/**
 * Finally, the main app
 */
extern "C" void app_main(void) {
  // Initialize and configure ADC 1
  adc_oneshot_unit_handle_t adc1_handle;
  adc_oneshot_unit_init_cfg_t init_config1 = {.unit_id = ADC_UNIT_1};
  ESP_ERROR_CHECK(adc_oneshot_new_unit(&init_config1, &adc1_handle));

  adc_oneshot_chan_cfg_t config = {
      .atten = ADC_ATTEN_DB_12,
      .bitwidth = ADC_BITWIDTH_DEFAULT,
  };
  ESP_ERROR_CHECK(
      adc_oneshot_config_channel(adc1_handle, pwr_btn_sns_chann, &config));

  adc_cali_handle_t adc1_cali_chan0_handle = NULL;
  bool do_calibration1_chan0 = adc_calibration_init(
      ADC_UNIT_1, pwr_btn_sns_chann, config.atten, &adc1_cali_chan0_handle);

  // Power pin config
  gpio_config_t io_conf = {
      .pin_bit_mask = (1ULL << pwr_in_ctrl_pin),
      .mode = GPIO_MODE_OUTPUT,
      .pull_up_en = GPIO_PULLUP_DISABLE,
      .pull_down_en = GPIO_PULLDOWN_DISABLE,
      .intr_type = GPIO_INTR_DISABLE,
  };

  ESP_ERROR_CHECK(gpio_config(&io_conf));

  // Hold up the power rail
  gpio_set_level(pwr_in_ctrl_pin, true);

  // Multiple drivers need NVS, settings infrastructure will initialize it.
  SettingsHandler &settings = SettingsHandler::shared();
  settings.init();

  // Init DMX Switcher before initializing any sources or sinks.
  DmxSwitcher &switcher = DmxSwitcher::get_switcher();
  ESP_ERROR_CHECK(switcher.init());

  // Immediately set the source and sync to the cached value.
  switcher.set_src_sink(settings.input, settings.output);
  switcher.set_output_en(settings.output_en);

  // Start onboard DMX
  TaskHandle_t onboard_dmx_task_handle;
  if (xTaskCreatePinnedToCore(onboard_dmx_task, "onboard_dmx", 4096,
                              &switcher.get_onboard_interface(), 3,
                              &onboard_dmx_task_handle, 1) != pdPASS ||
      onboard_dmx_task_handle == nullptr) {
    ESP_LOGE(TAG, "Failed to create onboard_dmx task");
    abort();
  }

  // Start TIMO
  TaskHandle_t timo_dmx_task_handle = nullptr;
  if (xTaskCreatePinnedToCore(timo_dmx_task, "timo_dmx", 4096,
                              &switcher.get_timo_interface(), 3,
                              &timo_dmx_task_handle, 1) != pdPASS ||
      timo_dmx_task_handle == nullptr) {
    ESP_LOGE(TAG, "Failed to create timo_dmx task");
    abort();
  }
  TaskNotifySettingsDelegate timo_task_notify_settings_change{
      timo_dmx_task_handle};
  settings.add_delegate(&timo_task_notify_settings_change);

  // Start HMI
  TaskHandle_t hmi_task_handle;
  if (xTaskCreatePinnedToCore(hmi_task, "hmi", 4096 * 4, nullptr, 4,
                              &hmi_task_handle, 0) != pdPASS ||
      hmi_task_handle == nullptr) {
    ESP_LOGE(TAG, "Failed to create hmi task");
    abort();
  }

  // Start Wifi task
  TaskHandle_t wifi_task_handle;
  if (xTaskCreatePinnedToCore(wifi_task, "wifi", 8192, nullptr, 3,
                              &wifi_task_handle, 0) != pdPASS ||
      wifi_task_handle == nullptr) {
    ESP_LOGE(TAG, "Failed to create wifi task");
    abort();
  }

  // Wait a milisecond for good luck
  vTaskDelay(pdMS_TO_TICKS(1));

  // Init graphics
  init_lvgl();

  // Finally, handle power in the main task
  uint64_t pwr_btn_press_start = 0;
  bool pwr_btn_released = false;
  while (1) {
    int adc_raw = 0;
    int adc_volts = 0;
    ESP_ERROR_CHECK(adc_oneshot_read(adc1_handle, pwr_btn_sns_chann, &adc_raw));
    if (do_calibration1_chan0) {
      ESP_ERROR_CHECK(
          adc_cali_raw_to_voltage(adc1_cali_chan0_handle, adc_raw, &adc_volts));
      if (adc_volts < pwr_btn_press_thresh_mv) {
        pwr_btn_released = true;
      }
      if (!pwr_btn_released || adc_volts < pwr_btn_press_thresh_mv) {
        pwr_btn_press_start = esp_timer_get_time();
      }

      if (esp_timer_get_time() - pwr_btn_press_start > 1000000) {
        ESP_LOGI(TAG, "Power button press detected, powering down.");
        vTaskDelay(pdMS_TO_TICKS(1000));
        gpio_set_level(pwr_in_ctrl_pin, false);
        vTaskDelay(portMAX_DELAY);
      }
    }

    vTaskDelay(pdMS_TO_TICKS(100));
  }

  // Tear Down
  ESP_ERROR_CHECK(adc_oneshot_del_unit(adc1_handle));
  if (do_calibration1_chan0) {
    adc_calibration_deinit(adc1_cali_chan0_handle);
  }

  settings.remove_delegate(&timo_task_notify_settings_change);

  switcher.deinit();

  vTaskDelete(onboard_dmx_task_handle);
}

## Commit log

2024-11-11 Hardware V0.1
    [crmx-bridge.kicad_pcb, crmx-bridge.kicad_sch, hmi.kicad_sch]
2024-11-11 updated to use FPC cable
    [crmx-bridge.kicad_pcb, crmx-bridge.kicad_sch]
2024-11-11 Updated 3d models
    [crmx-bridge.kicad_pcb, crmx-bridge.kicad_sch]
2024-11-11 before rearranging
    [bom-jlc.csv, bom-other.csv, bom.csv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]
2024-11-12 smaller isolated supplies integrated, may re-arrange some more
    [crmx-bridge.kicad_pcb]
2024-11-12 Rev to v0.2
    [bom-jlc.csv, bom-other.csv, bom.csv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]
2024-11-12 Finished layout with smaller power converters
    [crmx-bridge.kicad_pcb, positions-top.csv, positions.csv]
2024-11-20 Split up PCBs into separate files, Ordered V0.3
    [HMI Layout test 1.dxf, bom-jlc.csv, bom-other.csv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]
2025-01-06 added rotary encoder submodule
2025-01-23 patched encoder submodule
2025-07-19 Get settings working on display
    [crmx-bridge.kicad_sch, partitions.csv]
2025-07-19 remove rotary encoder submodule
2025-07-19 add rotary encoder component as manual fork
2025-07-19 Add SDKConfig
    [partitions.csv]
2025-07-19 hardcoded settings, fixed timo driver delays
    [TimoInterface.cc, TimoInterface.h, main.cc]
2025-07-20 Add wifi to the app and make some cleanups
    [partitions.csv]
